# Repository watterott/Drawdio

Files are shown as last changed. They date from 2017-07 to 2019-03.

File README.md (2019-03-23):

# Drawdio
Drawdio is an electronic pencil that makes music while you draw.
Essentially, it's a simple musical synthesizer that uses the conductive properties of pencil graphite to create different sounds.
The original design/idea is from [Jay Silver](http://drawdio.com).

Drawdio

* Assembly Instructions:
[English](https://github.com/watterott/Drawdio/raw/master/hardware/Drawdio_en.pdf), 
[German](https://github.com/watterott/Drawdio/raw/master/hardware/Drawdio_de.pdf), 
[Italian](https://github.com/watterott/Drawdio/raw/master/hardware/Drawdio_it.pdf)
* **[Documentation on learn.watterott.com](https://learn.watterott.com)**

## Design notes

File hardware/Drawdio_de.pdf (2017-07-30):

# Drawdio Bausatz

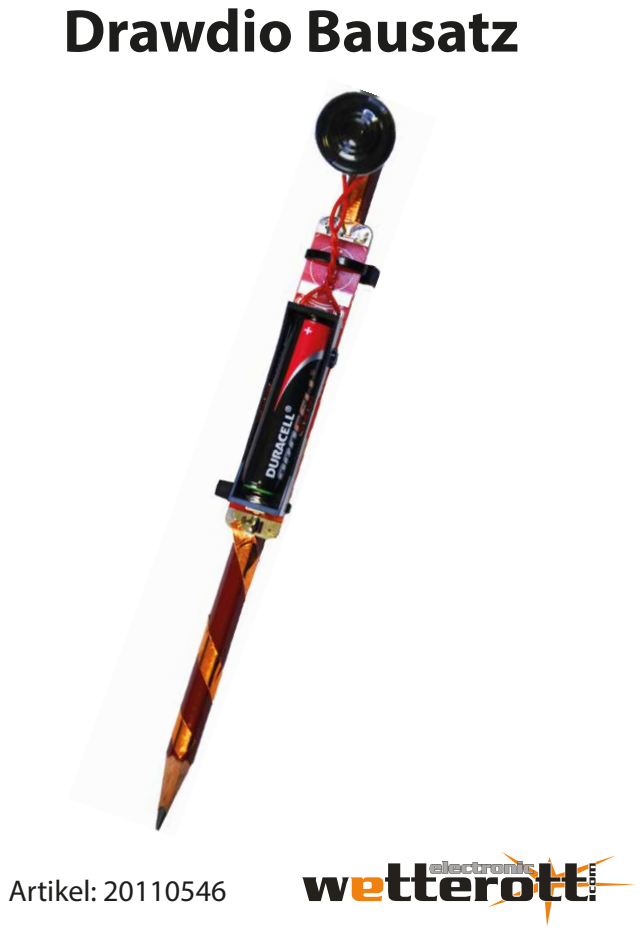
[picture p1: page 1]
Artikel: 20110546

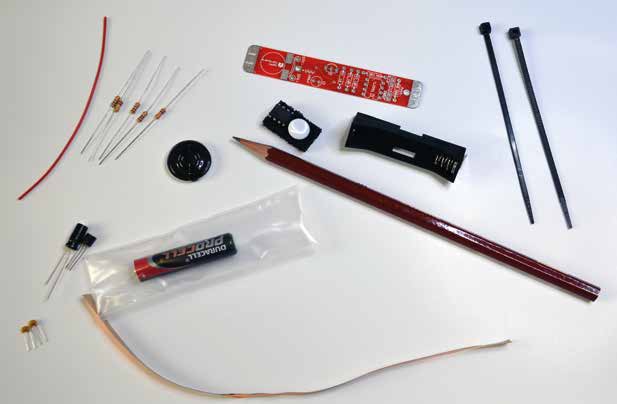
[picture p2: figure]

Bauteilliste:
- Bleistift, Reißzwecke, Kabelbinder
- Batteriehalter AAA + Batterie
- Leiterplatte
- Lautsprecher
- TLC551
- 100µF Kondensator
- 680pF Kondensator
- 100nF Kondensator
- Widerstand 270k Ohm
- Widerstand 10 Ohm
- 2x Widerstand 10M Ohm
- Widerstand 10k Ohm
- Transistor BC327
- 10cm Kupferband
- 10cm Schaltdraht

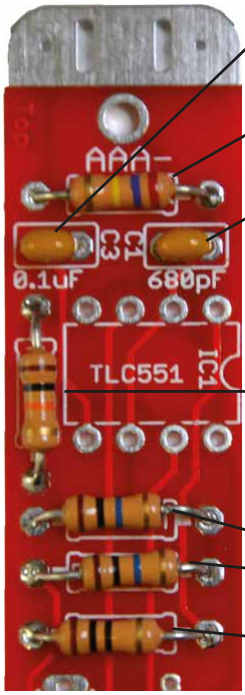
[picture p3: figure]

Widerstand 270k
rot-violett-gelb-gold
Kondensator 680pF
Markierung: 681

Kondensator 100nF
Markierung: 104

Widerstand 10k
braun-schwarz-orange-gold

Widerstand 10M
braun-schwarz-blau-gold oder braun-schwarz-schwarz-grün-braun Widerstand 10 Ohm
braun-schwarz-schwarz-gold

Als erstes werden die Widerstände und danach die Kondensatoren des Drawdios bestückt.
Bitte die Beschriftung der Kondensatoren beachten. Die Anschlussdrähte der Bauteile werden nach dem Verlöten mit einem Seitenschneider gekürzt, da die Lötseite später auf dem Bleistift auiegt.

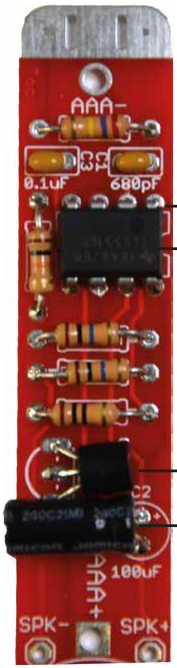
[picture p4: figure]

TLC551 (Richtung beachten)

BC327 Transistor
100µF Kondensator

Jetzt ist der 100µF Kondensator an der Reihe, diesen durch die Leiterplatte stecken (Polung beachten!) und um
90 Grad abwinkeln, dann verlöten. Der gleiche
Prozess ist auch beim Transistor nötig, da der Batteriehalter über diese Bauteile passen muss.
Als nächstes ist der TLC551 an der Reihe, der erste Pin (markiert durch einen Punkt auf dem IC) zeigt
zur Außenseite der Leiterplatte.
Zum Schluss wieder alle verlöteten Anschlüsse kürzen.

### 1. Pin

In diesem Schritt werden der Lautsprecher und der Batteriehalter montiert.

1. Den Schaltdraht in zwei gleich lange Stücke teilen und auf beiden Seiten abisolieren.
2. Den ersten Schaltdraht an SPK- und den zweiten an SPK+ auf der Leiterplatte anlöten, die beiden anderen Enden werden direkt an den Lautsprecher angelötet. Hierbei nicht zu lange mit dem Lötkolben am Lautsprecher arbeiten.
3. Nun folgt der Batteriehalter, hierbei wieder auf die Polung achten. Der + Pol des Halters zeigt zum Lautsprecher und ist auf der Leiterplatte mit AAA+ gekennzeichnet. Der Halter kann direkt auf den anderen Bauteilen auiegen.

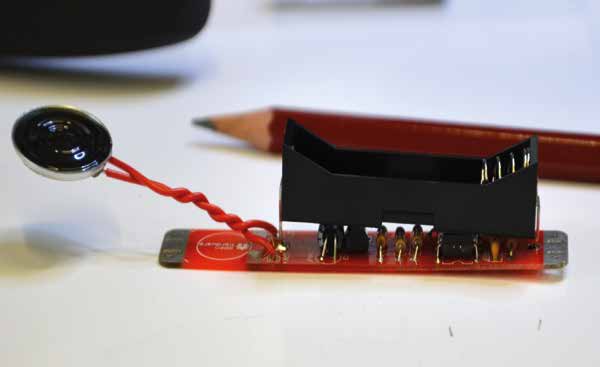
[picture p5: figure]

Nun folgt die Endmontage des Drawdios.

1. Die bestückte Platine wird etwa 2cm vom Ende des Bleistifts mit 2 Kabelbindern xiert.
2. Ein 3cm langes Stück des Kupferbandes wird nun
von der oberen Kontaktäche über das Ende des Bleistifts geklebt. Anschließend wird die Reißzwecke durch das Kupferband in den Bleistift gedrückt.
3. Das restliche Kupferband wird an die andere Kontakt-äche geklebt und um den Bleistift gewickelt.
Nun verlötet man noch die Kupferbänder mit den Kontakt-ächen, damit diese sich nicht mehr lösen.

Jetzt noch die Batterie einlegen und los gehts.

3 cm Kupferband

Reißzwecke

Kabelbinder

7 cm Kupferband

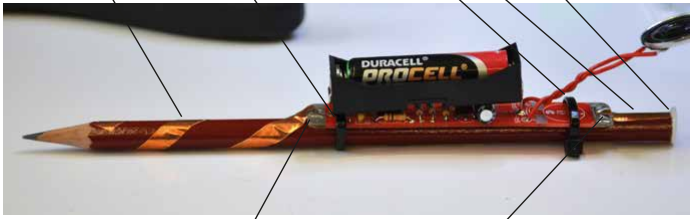
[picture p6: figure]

Kupferband und Leiterplatte verlöten

Bei Nichtgebrauch Batterie entfernen

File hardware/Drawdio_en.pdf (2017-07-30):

# Drawdio Kit

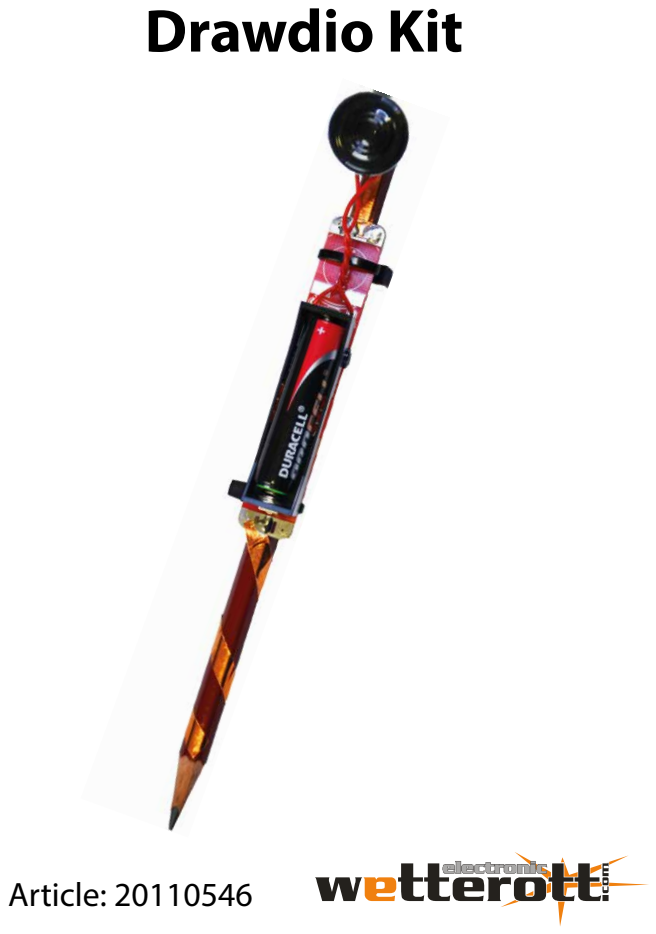
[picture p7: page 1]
Article: 20110546


Partlist:
- Pencil, Thumbtack, Cable-Ties
- Battery Holder + Battery
- PCB
- Speaker
- TLC551 IC
- 680pF Capacitor
- 100nF Capacitor
- 100µF electrolytic Capacitor
- 10 Ohm Resistor
- 10k Ohm Resistor
- 270k Ohm Resistor
- 2pcs 10M Ohm Resistor
- BC327 Transistor
- 10 cm Copper Tape
- 10 cm Wire

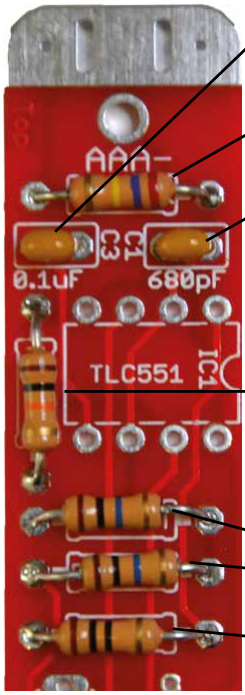
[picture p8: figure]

Resistor 270k
red-violet-yellow-gold
Cap 680pF
Marked: 681

Cap 100nF
Marked: K5K / 104

Resistor 10k
brown-black-orange-gold

Resistor 10M
brown-black-blue-gold or
brown-black-black-green-brown Resistor 10 Ohm
brown-black-black-gold

We are starting with soldering the resistors. You can identify the values on the colored rings. Now mount the two small capacitors and pay attention on the marking.
After soldering a component you can cut o
the pins on the soldering/bottom side of the PCB.

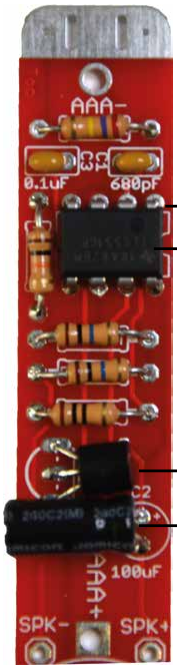
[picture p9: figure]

TLC551

Transistor BC327
100µF Pole cap

Now the 100uF pole capacitor can be mounted:
Bend the pins in right angle and pay attention on the right direction/polarity.
The minus pole is marked on the side of the cap.
The parts must be as low as possible, because the battery holder will be on top of this parts later. The transistor BC327 is mounted in the same way. Now we can start with the IC TLC551.
The rst pin is marked with a dot on the IC

### 1. Pin

The next step is the mounting of the speaker and the battery holder:

1. Cut the wire into two stripes and strip o the ends (3-5 mm is enough).
2. Solder the wires to the PCB, one to SPK- and one to SPK+. The other sides of the wires are connected to the speaker. Do not heat the speaker too long, this can cause a damage.
3. Now the battery holder can be soldered.
The plus contact of the holder is marked with AAA+ on the PCB. Mount it directly above the the other parts.


The last step is the assembling of the whole Drawdio.

1. The PCB is xed with the two cables ties on the pencil.
2. Cut a 3cm long stripe of the copper tape and tape it on the top side of the PCB/pencil. The thumbtack is pressed through the copper tape into the middle graphite of the pen.
3. The rest of the copper tape is taped around the pen on the other side.
4. Now you have to solder the copper tape to the contact of the PCB, because you need a good electronic connection of this two parts.
The Drawdio is ready for testing. Place the battery into the holder and have fun...

3cm Copper Tape

Thumbtack

Cable Ties

7cm Copper Tape

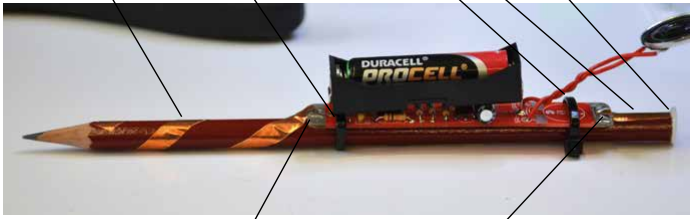
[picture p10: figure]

Here are two solder points for connecting the copper tape and the PCB

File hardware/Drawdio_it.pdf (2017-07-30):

# Drawdio Kit

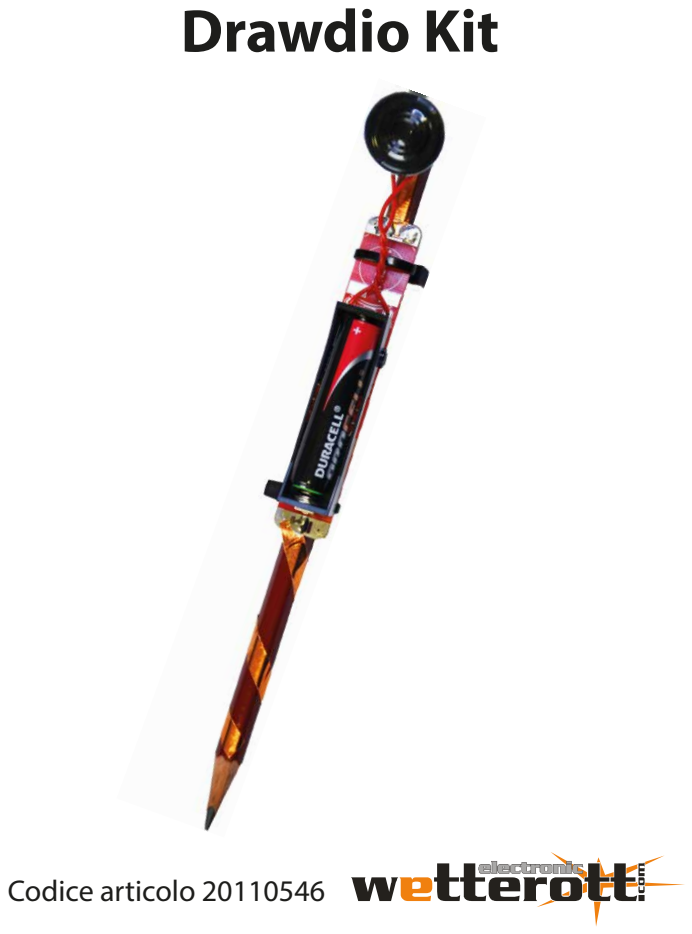
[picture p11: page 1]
Codice articolo 20110546


Elenco componenti:
- matita, puntina, fascette
- portabatteria AAA e batteria AAA
- circuito stampato
- altoparlante
- integrato TLC551
- condensatore 100µF elettrlitico.
- condensatore 680pF
- condensatore 100nF
- resistenza 270k Ohm
- resistenza 10 Ohm
- 2 resistenze 10M Ohm
- resistenza 10k Ohm
- transistor BC327
- 10 cm di nastro adesivo di rame
- 10 cm di cavo rigido


Resistenza 270kOhm
rosso viola giallo oro
Condensatore 680pF
codice sovraimpresso 681

Condensatore 100nF (0,1µF) codice sovraimpresso 104

Resistenza 10kOhm
marrone nero arancio oro

Resistenze 10MOhm
marrone nero blu oro
marrone nero nero verde marrone Resistenza 10 Ohm
marrone nero nero oro

Per prima cosa dobbiamo saldare le resistenze e i condensatori sulla scheda. Attenzione agli anelli colorati delle resistenze
e ai numeri stampati sui condensatori. Una volta saldati,
i li sono da accorciare con una tronchesino perché la schedina appoggia direttamente sulla matita.


TLC551
attenzione all'orientamento

transitore BC327
condensatore 100µF

Adesso saldiamo il condensatore da 100µF. I li sono da piegare di 90 gradi in modo che il lo più lungo vada nel buco “+“ e che il condensatore appoggi sulla schedina. Anche il transistor deve essere piegato in modo che la parte piatta appoggi sulla schedina per permettere il montaggio del portabatteria sopra questi componenti.
Dopo di questi saldiamo il TLC551. Il punto che indica il piedino numero uno deve trovarsi vicino al bordo della schedina. Dopo la saldatura tagliamo ancora i li.

### 1. Pin

Montaggio dell'altoparlante e del portabatteria.

1. Tagliare il lo in 2 pezzi uguali e toliere
l'isolante per 3 mm alle estremità.
2. Saldare un lo sul pin “SPK-“ della schedina e l'altro sul pin “SPK+“ e attorcigliarli. Le altre 2 estremità vengono saldate sull'altoparlante. Non riscaldare troppo a lungo l'altoparlante perché sennò potrebbe danneggiarsi.
3. Adesso saldiamo il postabatteria. Dobbiamo stare attenti alla polarità. Il polo positivo è rivolto verso l'altoparlante. Sulla schedina è segnalato con “AAA+“.
Il portabatteria può poggiare sui componenti sottostanti.


Montaggio nale.

1. Fissiamo la schedina ca. 2 cm sotto la parte terminale della matita con le fascette.
2. Incolliamo un pezzo di 3 cm di nastro di rame tra la schedina e il terminale della matita. Dopo
mettiamo la puntina e inseriamola attraverso il
nastro di rame nella mina della matita.
3. Il resto del nastro di rame lo attacchiamo sulla schedina e poi lo avvolgiamo tra la schedina e la punta della matita. Adesso saldiamo le strisce di nastro di rame sulla schedina per garantire un buon contatto.

Inserita la batteria, siamo pronti a partire.

3 cm nastro di rame

puntina

fascette

7 cm nastro di rame


punti di saldatura per ssare le strisce di nastro di rame

Rimuovere la batteria quando non in uso.

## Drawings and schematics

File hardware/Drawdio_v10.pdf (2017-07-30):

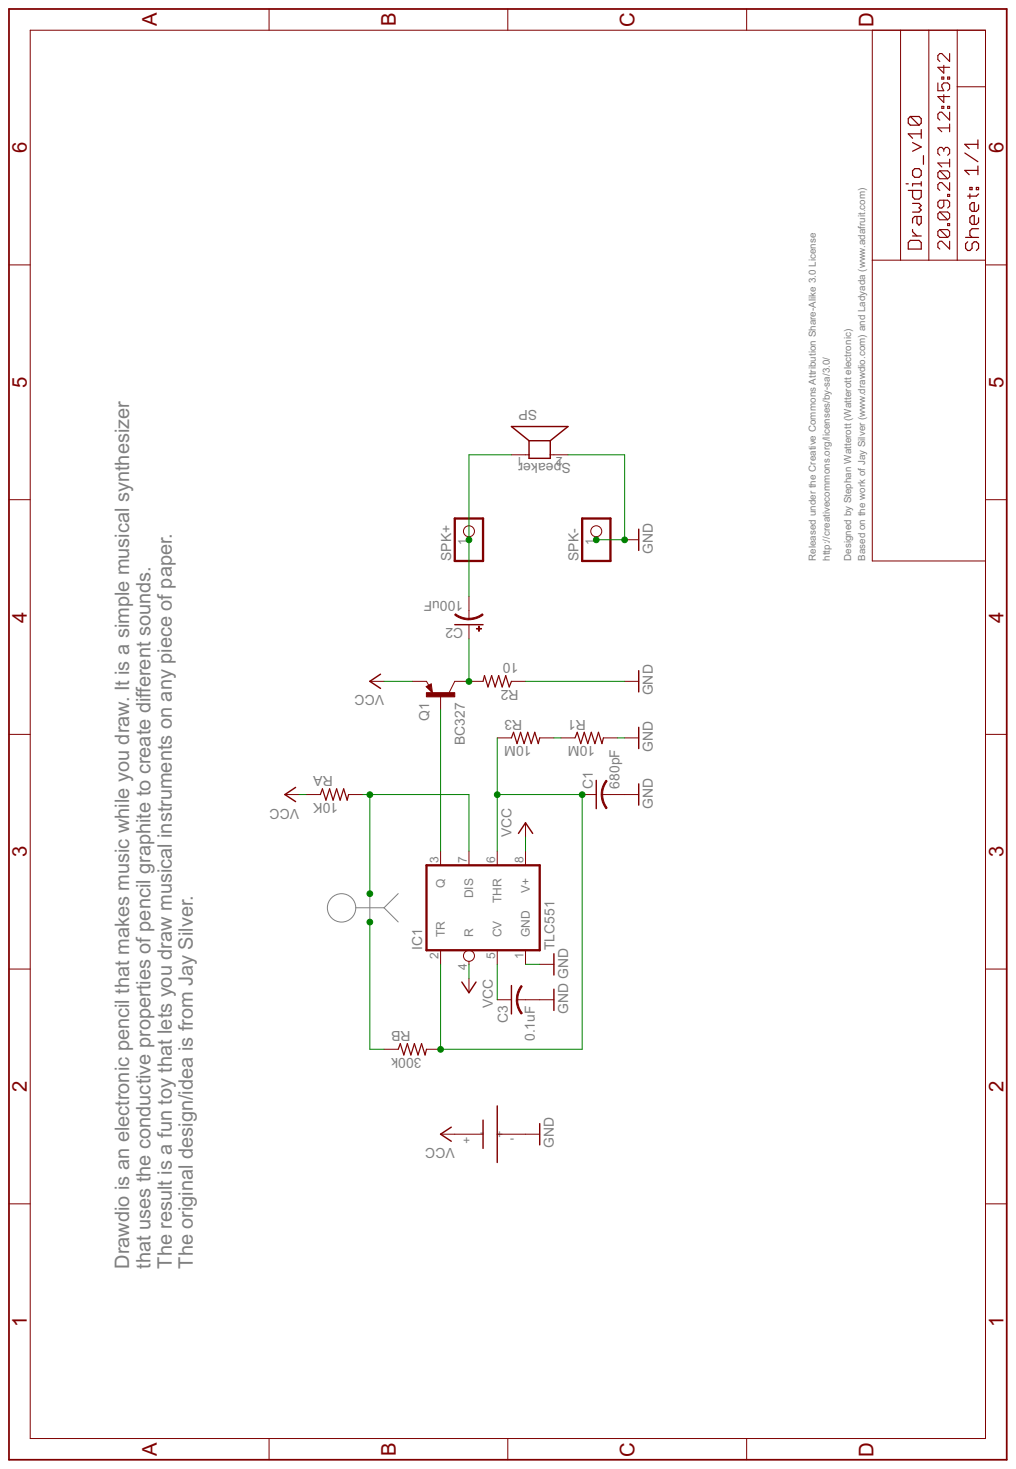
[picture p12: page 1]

VCC 0.1uF VCC k003 680pF K01 CCV CCV Fu001 CCV GND GND GND GND GND GND M01 01 TLC551 r ekaepS BC327 GND M01 Released under the Creative Commons Attribution Share-Alike 3.0 License http://creativecommons.org/licenses/by-sa/3.0/ Designed by Stephan Watterott (Watterott electronic) Based on the work of Jay Silver (w .drawdio.com) and Ladyada (w .adafruit.com) Drawdio is an electronic pencil that makes music while you draw. It is a simple musical synthesizer that uses the conductive properties of pencil graphite to create dif erent sounds. The result is a fun toy that lets you draw musical instruments on any piece of paper. The original design/idea is from Jay Silver. C3 BR C AR 1 2CSPK+ 1 SPK- 1 1R 2R IC1TR 2 Q 3 R 4 CV 5 THR 6 DIS 7 V+ 8 GND 1 PS 1 2 Q13R - - + + ABCD 1 2 3 4 5 6 ABCD 1 2 3 4 5 6

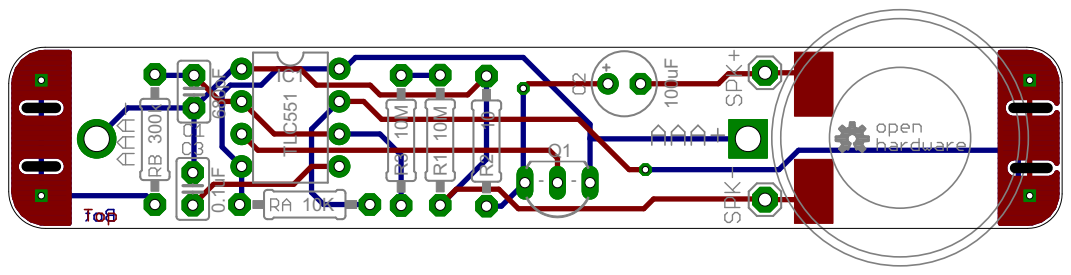
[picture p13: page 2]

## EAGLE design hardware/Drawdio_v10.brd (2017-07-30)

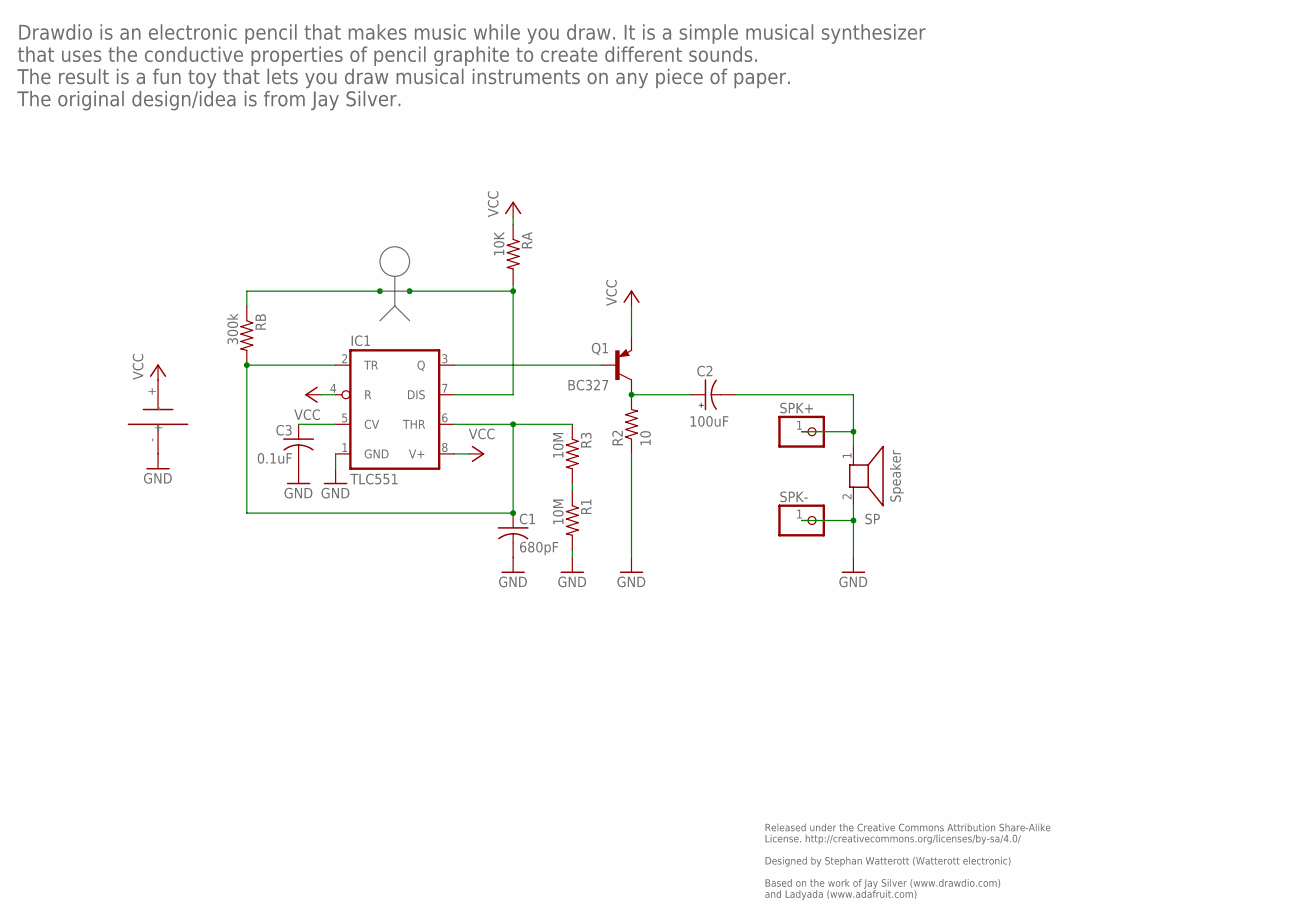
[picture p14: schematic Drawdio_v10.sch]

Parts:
C1: 680pF; C025-025X050
C2: 100uF; E2,5-5
C3: 0.1uF; C025-025X050
IC1: TLC551; DIL08
Q1: BC327; TO92-CBE
R1, R3: 10M; 0207/10
R2: 10; 0207/10
RA: 10K; 0207/10
RB: 300k; 0207/10
SP: Speaker; PS603
SPK+: PINHD-1X1; 1X01
SPK-: PINHD-1X1; 1X01
U$1: AAA

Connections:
GND: C1.2, C3.2, IC1.1 (GND), R1.2, R2.1, SP.2, SPK-.1, U$1.-
unnamed: C3.1, IC1.5 (CV)
unnamed: IC1.3 (Q), Q1.B
unnamed: C2.+, Q1.C, R2.2
unnamed: C1.1, IC1.2 (TR), IC1.6 (THR), R3.1, RB.2
unnamed: IC1.7 (DIS), RA.2
unnamed: C2.-, SP.1, SPK+.1
unnamed: R1.1, R3.2
VCC: IC1.4 (R), IC1.8 (V+), Q1.E, RA.1, U$1.+

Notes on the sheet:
Released under the Creative Commons Attribution Share-Alike License. http://creativecommons.org/licenses/by-sa/4.0/ Designed by Stephan Watterott (Watterott electronic) Based on the work of Jay Silver (www.drawdio.com) and Ladyada (www.adafruit.com)
Drawdio is an electronic pencil that makes music while you draw. It is a simple musical synthesizer that uses the conductive properties of pencil graphite to create different sounds. The result is a fun toy that lets you draw musical instruments on any piece of paper. The original design/idea is fr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

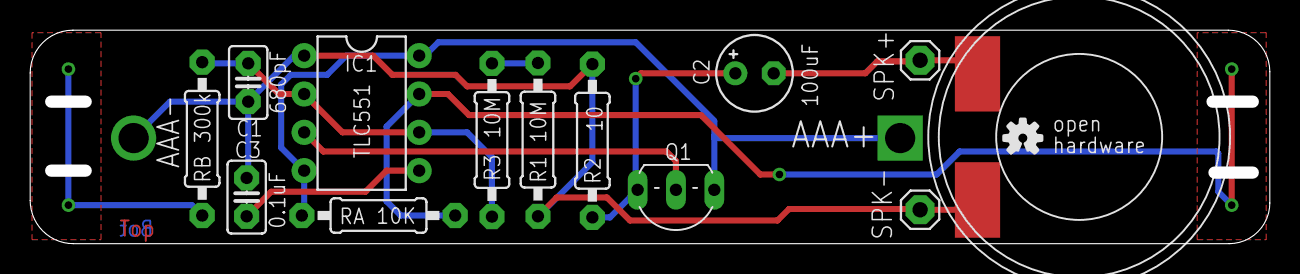
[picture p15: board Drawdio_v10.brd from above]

Board: 2 copper layers, 82.1 x 14.1 mm, 15 parts (1 on the bottom side), 9 nets.

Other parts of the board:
U$2: WE-LOGO
